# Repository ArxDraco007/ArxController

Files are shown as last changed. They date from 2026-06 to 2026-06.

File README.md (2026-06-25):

# ArxController

## What is this?
A fully custom controller. Customizable according to your console. Firmware, 3D Models, and PCB design.

## Why did I make this?
Making your own controller is absolutely amazing! The process gives you a complete learning of wiring peripherals, Double LDO circuits, Battery charging protection, and the ESP32-WROOM module. This journey has been absolutely wonderful, and I would recommend this project for all intermediate PCB designers.

## PICTURES-


ArxControllerV2sleek
ArxControllerV2Desert
ArxControllerV2

## Zine - 
zine (6)

## Build Instructions -
Soldering -
Start by applying flux to the pads on the footprint where you'll be soldering. Tin one of the pads with a small amount of solder, then carefully place your component onto the footprint. Touch your iron to the tinned pad to reflow it and tack the component in place, then let go with your tweezers once it's sitting right. Move to the opposite pad and solder it properly to the component. Finally, go back to your first pad and add a bit more solder to make sure you've got a solid joint.
Firmware - 
Plug in the ESP32-S3 via USB-C, select Board "ESP32S3 Dev Module" and the correct Port, hold BOOT while plugging in (or while pressing RESET) if it doesn't auto-detect, then click Upload to flash it, and finally press RESET or replug to run the new firmware.

## BOM

| Reference | Qty | Value | Footprint | Source | Buy Link |
|---|---|---|---|---|---|
| R2,R3 | 2 | 5.1k | Resistor_SMD:R_0603_1608Metric | Robu.in | [Link](https://robu.in/product/rc0603jr-075k1l-yageo-res-thick-film-0603-5-1k-ohm-5-0-1w1-10w-%C2%B1100ppm-c-pad-smd-t-r/) |
| R4 | 1 | 1.2k | Resistor_SMD:R_0603_1608Metric | LCSC | [Link](https://www.lcsc.com/search?q=0603+1.2K+ohm+resistor) |
| R5,R6,R7 | 3 | 1k | Resistor_SMD:R_0603_1608Metric | Robu.in | [Link](https://robu.in/product/1k-ohm-1-4w-0603-surface-mount-chip-resistor-pack-of-100/) |
| R8,R9 | 2 | 100R | Resistor_SMD:R_0603_1608Metric | LCSC | [Link](https://www.lcsc.com/search?q=0603+100R+1%25+resistor) |
| R10,R11,R12,R13,R14,R15,R16 | 7 | 100k | Resistor_SMD:R_0603_1608Metric | Robu.in | [Link](https://robu.in/product/100k-ohm-1-4w-0603-surface-mount-chip-resistor-pack-of-100/) |
| SW1 | 1 | EN (Tactile SMD) | Button_Switch_SMD:SW_SPST_TS-1088-xR020 | LCSC | [Link](https://www.lcsc.com/search?q=TS-1088) |
| SW2 | 1 | SW_PWR (Header) | Connector_PinSocket_2.54mm:PinSocket_1x03_P2.54mm_Vertical | Robu.in | [Link](https://robu.in/product/2-54mm-female-header-1x40-pin-strip/) |
| SW3 | 1 | BOOT (Tactile SMD) | custom_footprints:SW_SPST_TS-1088-xR020 | LCSC | [Link](https://www.lcsc.com/search?q=TS-1088) |
| SW4 | 1 | BTN_L (Shoulder switch) | custom_footprints:TS-1224VW | LCSC | [Link](https://www.lcsc.com/search?q=TS-1224VW) |
| SW5 | 1 | BTN_UP (Tactile 8mm) | custom_footprints:SW_PUSH_8mm_H5mm_custom | Robu.in | [Link](https://robu.in/product/6x6x5mm-tactile-push-button-switch-pack-of-10/) |
| SW6 | 1 | BTN_LEFT (Tactile 8mm) | custom_footprints:SW_PUSH_8mm_H5mm_custom | Robu.in | [Link](https://robu.in/product/6x6x5mm-tactile-push-button-switch-pack-of-10/) |
| SW7 | 1 | BTN_DOWN (Tactile 8mm) | custom_footprints:SW_PUSH_8mm_H5mm_custom | Robu.in | [Link](https://robu.in/product/6x6x5mm-tactile-push-button-switch-pack-of-10/) |
| SW8 | 1 | BTN_RIGHT (Tactile 8mm) | custom_footprints:SW_PUSH_8mm_H5mm_custom | Robu.in | [Link](https://robu.in/product/6x6x5mm-tactile-push-button-switch-pack-of-10/) |
| SW9 | 1 | BTN_START (Tactile 8mm) | custom_footprints:SW_PUSH_8mm_H5mm_custom | Robu.in | [Link](https://robu.in/product/6x6x5mm-tactile-push-button-switch-pack-of-10/) |
| SW10 | 1 | BTN_R (Shoulder switch) | custom_footprints:TS-1224VW | LCSC | [Link](https://www.lcsc.com/search?q=TS-1224VW) |
| SW11 | 1 | BTN_X (Tactile 8mm) | custom_footprints:SW_PUSH_8mm_H5mm_custom | Robu.in | [Link](https://robu.in/product/6x6x5mm-tactile-push-button-switch-pack-of-10/) |
| SW12 | 1 | BTN_A (Tactile 8mm) | custom_footprints:SW_PUSH_8mm_H5mm_custom | Robu.in | [Link](https://robu.in/product/6x6x5mm-tactile-push-button-switch-pack-of-10/) |
| SW13 | 1 | BTN_B (Tactile 8mm) | custom_footprints:SW_PUSH_8mm_H5mm_custom | Robu.in | [Link](https://robu.in/product/6x6x5mm-tactile-push-button-switch-pack-of-10/) |
| SW14 | 1 | BTN_Y (Tactile 8mm) | custom_footprints:SW_PUSH_8mm_H5mm_custom | Robu.in | [Link](https://robu.in/product/6x6x5mm-tactile-push-button-switch-pack-of-10/) |
| SW15 | 1 | BTN_SELECT (Tactile 8mm) | custom_footprints:SW_PUSH_8mm_H5mm_custom | Robu.in | [Link](https://robu.in/product/6x6x5mm-tactile-push-button-switch-pack-of-10/) |
| SW16 | 1 | BTN_SYS (Tactile 8mm) | custom_footprints:SW_PUSH_8mm_H5mm_custom | Robu.in | [Link](https://robu.in/product/6x6x5mm-tactile-push-button-switch-pack-of-10/) |
| TP1,TP3,TP5 | 3 | TestPoint | TestPoint:TestPoint_Pad_D2.0mm | Robu.in | [Link](https://robu.in/product/2mm-pin-female-header-1x40/) |
| TP4 | 1 | AMS_3V3 (TestPoint) | TestPoint:TestPoint_Pad_D2.0mm | Robu.in | [Link](https://robu.in/product/2mm-pin-female-header-1x40/) |
| U1 | 1 | ESP32-S3-WROOM-1-N16R8 | RF_Module:ESP32-S3-WROOM-1 | Robu.in | [Link](https://robu.in/product/espressif-esp32-s3-wroom-1-n16r8-module/) |
| U2 | 1 | MIC5219-3.3YM5 | Package_TO_SOT_SMD:SOT-23-5 | Robu.in | [Link](https://robu.in/product/mic5219-3-3ym5-tr-microchip-fixed-ldo-voltage-regulator-2-5v-to-12v-350mv-dropout-3-3vout-500maout-sot-23-5/) |
| U3 | 1 | TP4056-42-ESOP8 | Package_SO:SOIC-8-1EP_3.9x4.9mm_P1.27mm_EP2.41x3.3mm_ThermalVias | Robu.in | [Link](https://robu.in/product/tp4056-top-power-asic-4-2v-1a-standalone-linear-li-ion-battery-charger-with-thermal-regulation-sop8/) |
| U4 | 1 | DW01A | Package_TO_SOT_SMD:SOT-23-6 | Robu.in | [Link](https://robu.in/product/dw01a-4-3v-lithium-ion-lithium-polymer-battery-protection-ic-6pin-sot-23/) |
| U5 | 1 | AMS1117-3.3 | Package_TO_SOT_SMD:SOT-223-3_TabPin2 | Robu.in | [Link](https://robu.in/product/ams1117-3-3-slkor-800ma-70db120hz-fixed-3-3v-positive-electrode-18v-sot-223-voltage-regulators-linear-low-drop-out-ldo-regulators-rohs/) |
| U6 | 1 | PCM5102APWR | TSSOP-20 | Robu.in | [Link](https://robu.in/product/pcm5102apwr-texas-instruments-digital-to-analogue-converter-32-bit-384-ksps-i2s-3v-to-3-6v-tssop-20-pins/) |
| U7 | 1 | TPA2012D2 | QFN-16 | LCSC | [Link](https://www.lcsc.com/search?q=TPA2012D2) |
| U8 | 1 | ILI9341 TFT 2.4/2.8" Display Module | SPI 240x320 | LCSC | [Link](https://www.lcsc.com/search?q=ILI9341+2.8+SPI) |
| U9 | 1 | MAX17048G+T10 | SOT-23-6 (USOP-8) | LCSC | [Link](https://www.lcsc.com/search?q=MAX17048) |
| U10 | 1 | XC6220 LDO | SOT-23-5 | LCSC | [Link](https://www.lcsc.com/search?q=XC6220) |
| - | 1 | microSD Card Slot (Push-Push) | SMD microSD Socket | Robu.in | [Link](https://robu.in/product/micro-sd-card-tf-card-memory-card-socket-push-push-type-smd/) |
| - | 1 | USB-C Connector (16-pin) | USB_C_Receptacle_USB2.0_16P | Robu.in | [Link](https://robu.in/product/usb-type-c-16-pin-female-connector-smd/) |
| HW1-HW4 | 4 | M3 × 22mm Machine Screw | Mechanical:MountingHardware | element14 | [Link](https://in.element14.com/tr-fastenings/tr00008755-000/screw-flat-csk-head-sltd-m3-22mm/dp/4156380) |
| HW5-HW8 | 4 | M3 Hex Nut | Mechanical:MountingHardware | FlyRobo | [Link](https://www.flyrobo.in/m3-ss-hex-nut-10pcs?srsltid=AfmBOopC71qpsOIubiWPyQa1-qcC8mzI4XCSzNWDzo-gBculU_eEorxn) |
| FNIRSI HS-02 | 1 | Soldering | Soldering Iron | FNIRSI | [Link]("https://rees52.com/products/fnirsi-hs-01-intelligent-soldering-iron-hs-01-intelligent-temperature-controlled-soldering-iron-hs-01-automatic-sleep-mode-soldering-stat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")

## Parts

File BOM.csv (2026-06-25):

Reference | Qty | Value | Footprint | Source | Buy Link (India)
R2,R3 | 2 | 5.1k | Resistor_SMD:R_0603_1608Metric | Robu.in | https://robu.in/product/rc0603jr-075k1l-yageo-res-thick-film-0603-5-1k-ohm-5-0-1w1-10w-%C2%B1100ppm-c-pad-smd-t-r/
R4 | 1 | 1.2k | Resistor_SMD:R_0603_1608Metric | LCSC | https://www.lcsc.com/search?q=0603+1.2K+ohm+resistor
R5,R6,R7 | 3 | 1k | Resistor_SMD:R_0603_1608Metric | Robu.in | https://robu.in/product/1k-ohm-1-4w-0603-surface-mount-chip-resistor-pack-of-100/
R8,R9 | 2 | 100R | Resistor_SMD:R_0603_1608Metric | LCSC | https://www.lcsc.com/search?q=0603+100R+1%25+resistor
R10,R11,R12,R13,R14,R15,R16 | 7 | 100k | Resistor_SMD:R_0603_1608Metric | Robu.in | https://robu.in/product/100k-ohm-1-4w-0603-surface-mount-chip-resistor-pack-of-100/
SW1 | 1 | EN (Tactile SMD) | Button_Switch_SMD:SW_SPST_TS-1088-xR020 | LCSC | https://www.lcsc.com/search?q=TS-1088
SW2 | 1 | SW_PWR (Header) | Connector_PinSocket_2.54mm:PinSocket_1x03_P2.54mm_Vertical | Robu.in | https://robu.in/product/2-54mm-female-header-1x40-pin-strip/
SW3 | 1 | BOOT (Tactile SMD) | custom_footprints:SW_SPST_TS-1088-xR020 | LCSC | https://www.lcsc.com/search?q=TS-1088
SW4 | 1 | BTN_L (Shoulder switch) | custom_footprints:TS-1224VW | LCSC | https://www.lcsc.com/search?q=TS-1224VW
SW5 | 1 | BTN_UP (Tactile 8mm) | custom_footprints:SW_PUSH_8mm_H5mm_custom | Robu.in | https://robu.in/product/6x6x5mm-tactile-push-button-switch-pack-of-10/
SW6 | 1 | BTN_LEFT (Tactile 8mm) | custom_footprints:SW_PUSH_8mm_H5mm_custom | Robu.in | https://robu.in/product/6x6x5mm-tactile-push-button-switch-pack-of-10/
SW7 | 1 | BTN_DOWN (Tactile 8mm) | custom_footprints:SW_PUSH_8mm_H5mm_custom | Robu.in | https://robu.in/product/6x6x5mm-tactile-push-button-switch-pack-of-10/
SW8 | 1 | BTN_RIGHT (Tactile 8mm) | custom_footprints:SW_PUSH_8mm_H5mm_custom | Robu.in | https://robu.in/product/6x6x5mm-tactile-push-button-switch-pack-of-10/
SW9 | 1 | BTN_START (Tactile 8mm) | custom_footprints:SW_PUSH_8mm_H5mm_custom | Robu.in | https://robu.in/product/6x6x5mm-tactile-push-button-switch-pack-of-10/
SW10 | 1 | BTN_R (Shoulder switch) | custom_footprints:TS-1224VW | LCSC | https://www.lcsc.com/search?q=TS-1224VW
SW11 | 1 | BTN_X (Tactile 8mm) | custom_footprints:SW_PUSH_8mm_H5mm_custom | Robu.in | https://robu.in/product/6x6x5mm-tactile-push-button-switch-pack-of-10/
SW12 | 1 | BTN_A (Tactile 8mm) | custom_footprints:SW_PUSH_8mm_H5mm_custom | Robu.in | https://robu.in/product/6x6x5mm-tactile-push-button-switch-pack-of-10/
SW13 | 1 | BTN_B (Tactile 8mm) | custom_footprints:SW_PUSH_8mm_H5mm_custom | Robu.in | https://robu.in/product/6x6x5mm-tactile-push-button-switch-pack-of-10/
SW14 | 1 | BTN_Y (Tactile 8mm) | custom_footprints:SW_PUSH_8mm_H5mm_custom | Robu.in | https://robu.in/product/6x6x5mm-tactile-push-button-switch-pack-of-10/
SW15 | 1 | BTN_SELECT (Tactile 8mm) | custom_footprints:SW_PUSH_8mm_H5mm_custom | Robu.in | https://robu.in/product/6x6x5mm-tactile-push-button-switch-pack-of-10/
SW16 | 1 | BTN_SYS (Tactile 8mm) | custom_footprints:SW_PUSH_8mm_H5mm_custom | Robu.in | https://robu.in/product/6x6x5mm-tactile-push-button-switch-pack-of-10/
TP1,TP3,TP5 | 3 | TestPoint | TestPoint:TestPoint_Pad_D2.0mm | Robu.in | https://robu.in/product/2mm-pin-female-header-1x40/
TP4 | 1 | AMS_3V3 (TestPoint) | TestPoint:TestPoint_Pad_D2.0mm | Robu.in | https://robu.in/product/2mm-pin-female-header-1x40/
U1 | 1 | ESP32-S3-WROOM-1-N16R8 | RF_Module:ESP32-S3-WROOM-1 | Robu.in | https://robu.in/product/espressif-esp32-s3-wroom-1-n16r8-module/
U2 | 1 | MIC5219-3.3YM5 | Package_TO_SOT_SMD:SOT-23-5 | Robu.in | https://robu.in/product/mic5219-3-3ym5-tr-microchip-fixed-ldo-voltage-regulator-2-5v-to-12v-350mv-dropout-3-3vout-500maout-sot-23-5/
U3 | 1 | TP4056-42-ESOP8 | Package_SO:SOIC-8-1EP_3.9x4.9mm_P1.27mm_EP2.41x3.3mm_ThermalVias | Robu.in | https://robu.in/product/tp4056-top-power-asic-4-2v-1a-standalone-linear-li-ion-battery-charger-with-thermal-regulation-sop8/
U4 | 1 | DW01A | Package_TO_SOT_SMD:SOT-23-6 | Robu.in | https://robu.in/product/dw01a-4-3v-lithium-ion-lithium-polymer-battery-protection-ic-6pin-sot-23/
U5 | 1 | AMS1117-3.3 | Package_TO_SOT_SMD:SOT-223-3_TabPin2 | Robu.in | https://robu.in/product/ams1117-3-3-slkor-800ma-70db120hz-fixed-3-3v-positive-electrode-18v-sot-223-voltage-regulators-linear-low-drop-out-ldo-regulators-rohs/
U6 | 1 | PCM5102APWR | TSSOP-20 | Robu.in | https://robu.in/product/pcm5102apwr-texas-instruments-digital-to-analogue-converter-32-bit-384-ksps-i2s-3v-to-3-6v-tssop-20-pins/
U7 | 1 | TPA2012D2 | QFN-16 | LCSC | https://www.lcsc.com/search?q=TPA2012D2
U8 | 1 | ILI9341 TFT 2.4 Display Module | SPI 240x320 | LCSC | https://www.lcsc.com/search?q=ILI9341+2.8+SPI
U9 | 1 | MAX17048G+T10 | SOT-23-6 (USOP-8) | LCSC | https://www.lcsc.com/search?q=MAX17048
U10 | 1 | XC6220 LDO | SOT-23-5 | LCSC | https://www.lcsc.com/search?q=XC6220
MicroSD | 1 | microSD Card Slot (Push-Push) | SMD microSD Socket | Robu.in | https://robu.in/product/micro-sd-card-tf-card-memory-card-socket-push-push-type-smd/
USB Connector Pin | 1 | USB-C Connector (16-pin) | USB_C_Receptacle_USB2.0_16P | Robu.in | https://robu.in/product/usb-type-c-16-pin-female-connector-smd/
HW1-HW4 | 4 | M3 × 22mm Machine Screw | Mechanical:MountingHardware | element14 | https://in.element14.com/tr-fastenings/tr00008755-000/screw-flat-csk-head-sltd-m3-22mm/dp/4156380
HW5-HW8 | 4 | M3 Hex Nut | Mechanical:MountingHardware | FlyRobo | https://www.flyrobo.in/m3-ss-hex-nut-10pcs
FNIRSI HS-02 | 1 | Soldering | Soldering Iron | FNIRSI | https://rees52.com/products/fnirsi-hs-01-intelligent-soldering-iron-hs-01-intelligent-temperature-controlled-soldering-iron-hs-01-automatic-sleep-mode-solderi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

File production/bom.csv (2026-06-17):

Designator | Footprint | Quantity | Value | LCSC Part #
C1, C13, C3 | 0603 | 3 | 100nF
C10, C4, C5, C6 | 0603 | 4 | 10uF
C11 | CP_EIA-3216-18_Kemet-A | 1 | 10uF
C12 | CP_EIA-3216-18_Kemet-A | 1 | 22uF
C2 | 0603 | 1 | 22nF
C7, C8, C9 | 0603 | 3 | 100uF
D1 | 0603 | 1 | RED
D2 | 0603 | 1 | BLUE
J1 | USB_C_Receptacle_GCT_USB4105-xx-A_16P_TopMnt_Horizontal | 1 | USB_C_Receptacle_USB2.0_16P
J2 | JST_ZH_S2B-ZR-SM4A-TF_1x02-1MP_P1.50mm_Horizontal | 1 | BATT_Conn
J4 | OLED128x32_1x04_P2.54mm_socket | 1 | OLED_Conn
Q1 | SOT-23-6L_TCP | 1 | ~
Q2 | SOT-23 | 1 | PMOS
R1, R17 | 0603 | 2 | 10k
R10, R11, R12, R13, R14, R15, R16 | 0603 | 7 | 100k
R2, R3 | 0603 | 2 | 5.1k
R4 | 0603 | 1 | 1.2k
R5, R6, R7 | 0603 | 3 | 1k
R8, R9 | 0603 | 2 | 100R
SW1 | SW_SPST_TS-1088-xR020 | 1 | EN
SW10 | TS-1224VW | 1 | BTN_R
SW11 | SW_PUSH_8mm_H5mm_custom | 1 | BTN_X
SW12 | SW_PUSH_8mm_H5mm_custom | 1 | BTN_A
SW13 | SW_PUSH_8mm_H5mm_custom | 1 | BTN_B
SW14 | SW_PUSH_8mm_H5mm_custom | 1 | BTN_Y
SW15 | SW_PUSH_8mm_H5mm_custom | 1 | BTN_SELECT
SW16 | SW_PUSH_8mm_H5mm_custom | 1 | BTN_SYS
SW2 | PinSocket_1x03_P2.54mm_Vertical | 1 | SW_PWR
SW3 | SW_SPST_TS-1088-xR020 | 1 | BOOT
SW4 | TS-1224VW | 1 | BTN_L
SW5 | SW_PUSH_8mm_H5mm_custom | 1 | BTN_UP
SW6 | SW_PUSH_8mm_H5mm_custom | 1 | BTN_LEFT
SW7 | SW_PUSH_8mm_H5mm_custom | 1 | BTN_DOWN
SW8 | SW_PUSH_8mm_H5mm_custom | 1 | BTN_RIGHT
SW9 | SW_PUSH_8mm_H5mm_custom | 1 | BTN_START
TP1, TP3, TP5 | TestPoint_Pad_D2.0mm | 3 | TestPoint
TP4 | TestPoint_Pad_D2.0mm | 1 | AMS_3V3
U1 | ESP32-S3-WROOM-1 | 1 | ESP32-S3-WROOM-1
U2 | SOT-23-5 | 1 | MIC5219-3.3YM5
U3 | SOIC-8-1EP_3.9x4.9mm_P1.27mm_EP2.41x3.3mm_ThermalVias | 1 | TP4056-42-ESOP8
U4 | SOT-23-6 | 1 | DW01A
U5 | SOT-223-3_TabPin2 | 1 | AMS1117-3.3

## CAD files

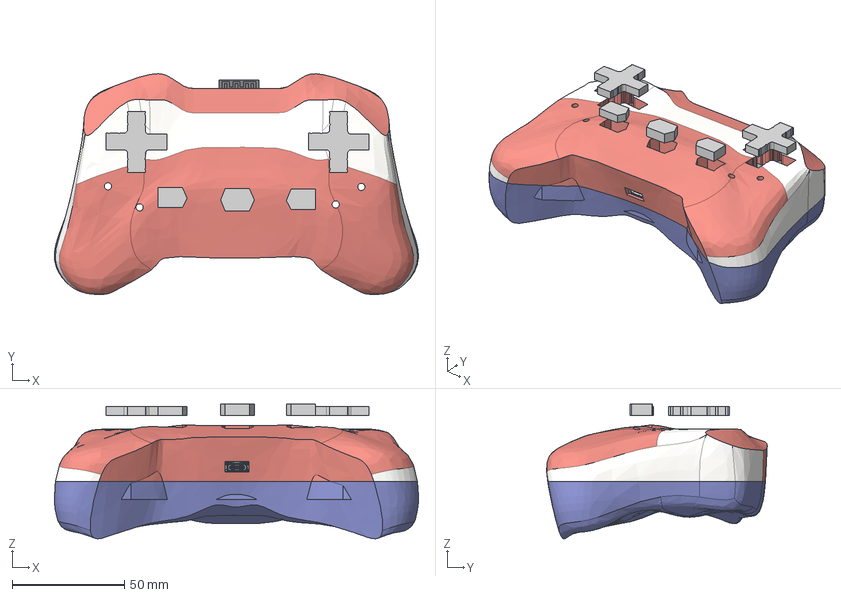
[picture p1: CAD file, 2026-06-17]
CAD/Assembly.step
162.0 x 98.2 x 59.9 mm

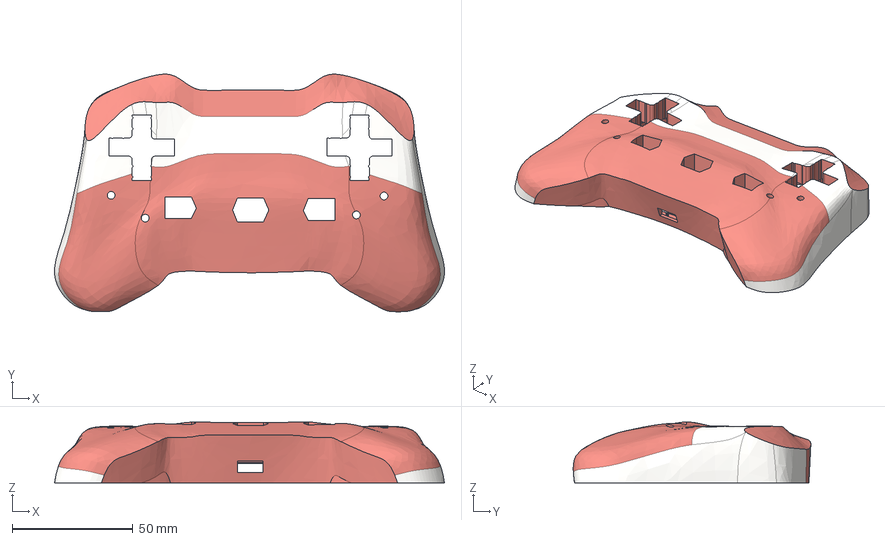
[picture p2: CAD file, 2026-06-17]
CAD/top.step
161.2 x 98.3 x 25.2 mm

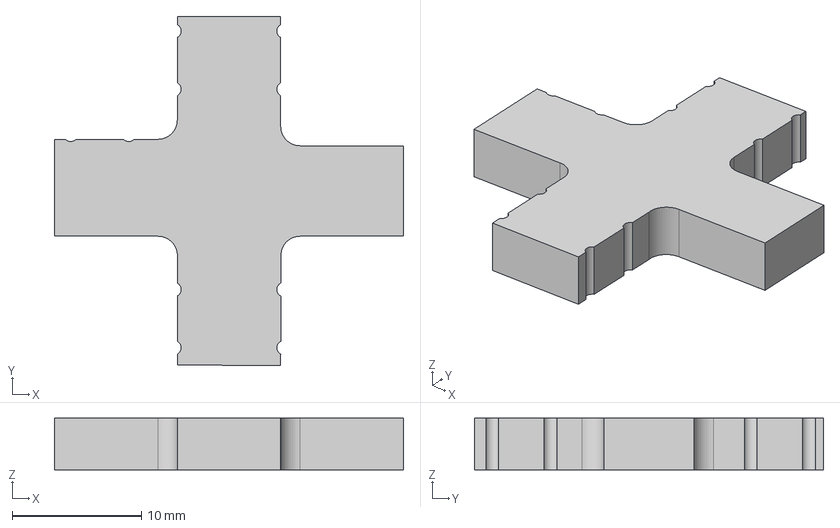
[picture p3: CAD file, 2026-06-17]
CAD/plusbutton.step
27.0 x 27.0 x 4.00 mm

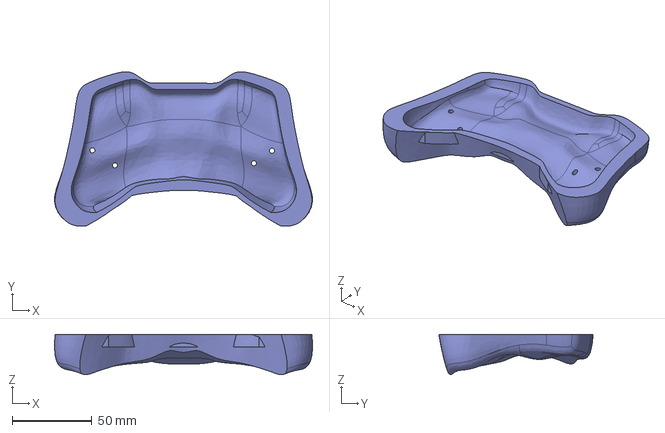
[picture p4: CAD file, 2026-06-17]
CAD/bottom.step
162.0 x 96.9 x 25.4 mm

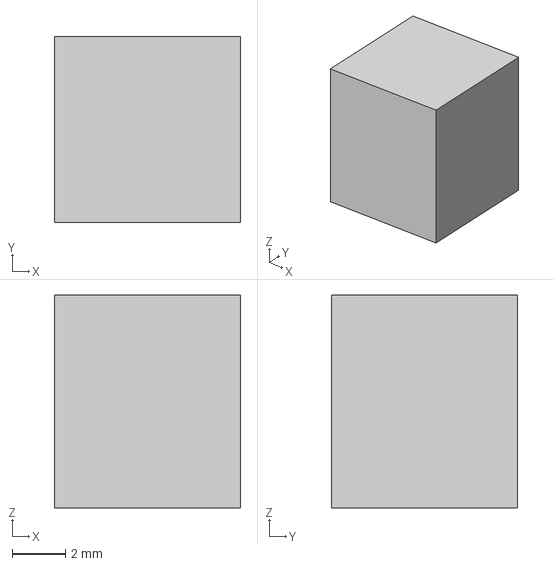
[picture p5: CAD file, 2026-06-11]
CAD/squarebutton.step
7.00 x 7.00 x 8.00 mm
91292A020_18-8 Stainless Steel Socket Head Screw
90870A113_Zinc-Plated High-Strength Steel Hex Nut x 8

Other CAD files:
CAD/Assembly.f3z

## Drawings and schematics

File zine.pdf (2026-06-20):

# ARX

# CONTROLLER

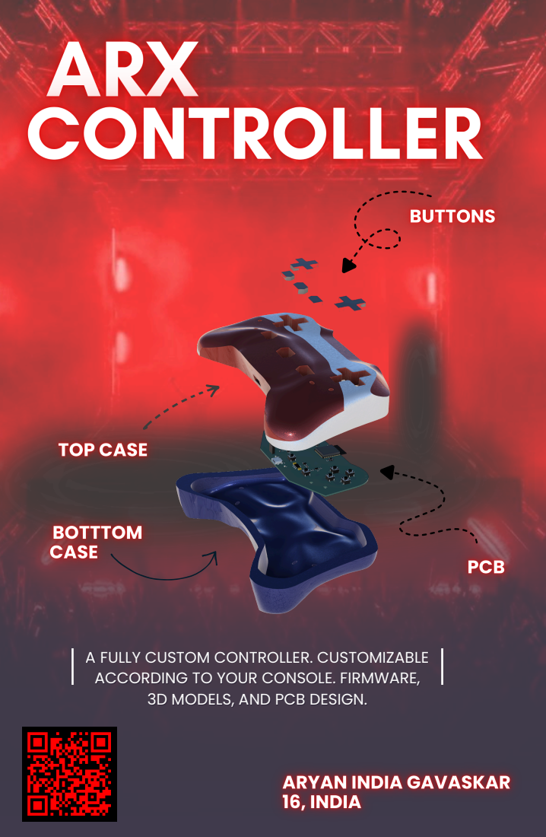
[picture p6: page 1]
BOTTTOM CASE; PCB; TOP CASE; BUTTONS

A FULLY CUSTOM CONTROLLER. CUSTOMIZABLE
ACCORDING TO YOUR CONSOLE. FIRMWARE,
3D MODELS, AND PCB DESIGN.

ARYAN INDIA GAVASKAR
16, INDIA

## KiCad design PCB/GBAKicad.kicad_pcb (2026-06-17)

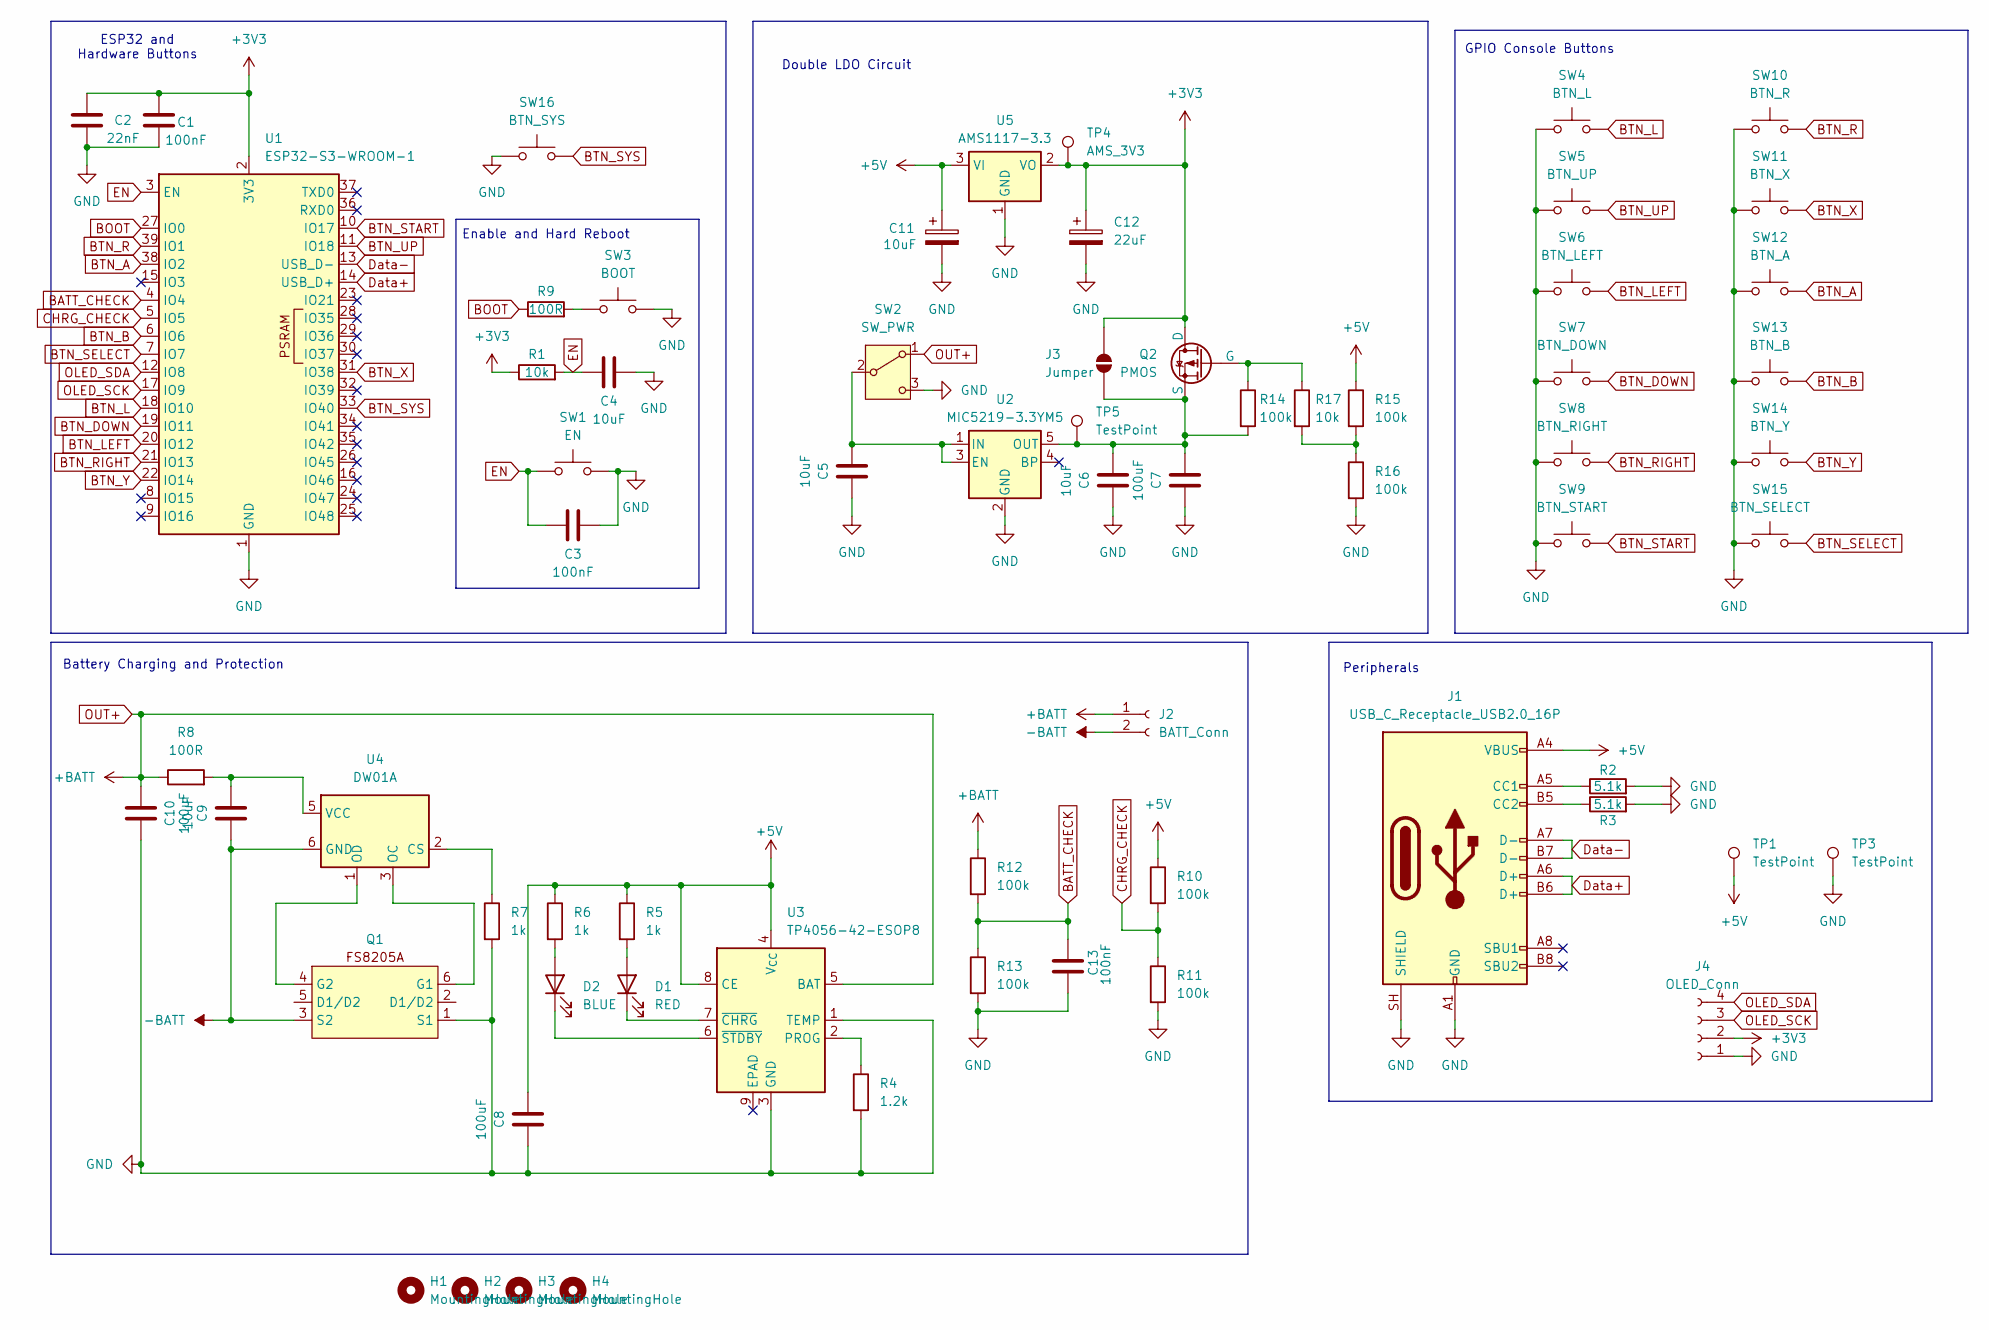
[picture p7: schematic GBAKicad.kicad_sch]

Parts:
C1, C3, C13: 100nF; C_0603_1608Metric
C2: 22nF; C_0603_1608Metric
C4, C5, C6, C10: 10uF; C_0603_1608Metric
C7, C8, C9: 100uF; C_0603_1608Metric
C11: 10uF; CP_EIA-3216-18_Kemet-A
C12: 22uF; CP_EIA-3216-18_Kemet-A
D1: RED; LED_0603_1608Metric
D2: BLUE; LED_0603_1608Metric
H1, H2, H3, H4: MountingHole; MountingHole_3.2mm_M3
J1: USB_C_Receptacle_USB2.0_16P; USB_C_Receptacle_GCT_USB4105-xx-A_16P_TopMnt_Horizontal
J2: BATT_Conn; JST_ZH_S2B-ZR-SM4A-TF_1x02-1MP_P1.50mm_Horizontal
J3: Jumper; R_0603_1608Metric
J4: OLED_Conn; OLED128x32_1x04_P2.54mm_socket
Q1: SOT-23-6L_TCP
Q2: PMOS; SOT-23
R1, R17: 10k; R_0603_1608Metric
R2, R3: 5.1k; R_0603_1608Metric
R4: 1.2k; R_0603_1608Metric
R5, R6, R7: 1k; R_0603_1608Metric
R8, R9: 100R; R_0603_1608Metric
R10, R11, R12, R13, R14, R15, R16: 100k; R_0603_1608Metric
SW1: EN; SW_SPST_TS-1088-xR020
SW2: SW_PWR; PinSocket_1x03_P2.54mm_Vertical
SW3: BOOT; SW_SPST_TS-1088-xR020
SW4: BTN_L; TS-1224VW
SW5: BTN_UP; SW_PUSH_8mm_H5mm_custom
SW6: BTN_LEFT; SW_PUSH_8mm_H5mm_custom
SW7: BTN_DOWN; SW_PUSH_8mm_H5mm_custom
SW8: BTN_RIGHT; SW_PUSH_8mm_H5mm_custom
SW9: BTN_START; SW_PUSH_8mm_H5mm_custom
SW10: BTN_R; TS-1224VW
SW11: BTN_X; SW_PUSH_8mm_H5mm_custom
SW12: BTN_A; SW_PUSH_8mm_H5mm_custom
SW13: BTN_B; SW_PUSH_8mm_H5mm_custom
SW14: BTN_Y; SW_PUSH_8mm_H5mm_custom
SW15: BTN_SELECT; SW_PUSH_8mm_H5mm_custom
SW16: BTN_SYS; SW_PUSH_8mm_H5mm_custom
TP1, TP3, TP5: TestPoint; TestPoint_Pad_D2.0mm
TP4: AMS_3V3; TestPoint_Pad_D2.0mm
U1: ESP32-S3-WROOM-1
U2: MIC5219-3.3YM5; SOT-23-5
U3: TP4056-42-ESOP8; SOIC-8-1EP_3.9x4.9mm_P1.27mm_EP2.41x3.3mm_ThermalVias
U4: DW01A; SOT-23-6
U5: AMS1117-3.3; SOT-223-3_TabPin2

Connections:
+3V3: C1.2, C2.2, C12.1, J3.2 (B), J4.2, Q2.1 (D), R1.1, TP4.1 (1_1), U1.2 (3V3), U5.2 (VO)
+5V: C8.1, C11.1, J1.A4 (VBUS), J1.A9 (VBUS), J1.B4 (VBUS), J1.B9 (VBUS), R5.1, R6.1, R10.1, R15.1, TP1.1 (1_1), U3.4 (V_{CC}), U3.8 (CE), U5.3 (VI)
-BATT: C9.2, J2.2, Q1.3 (S2), U4.6 (GND)
BATT_CHECK: C13.1, R12.2, R13.1, U1.4 (IO4)
BOOT: R9.1, U1.27 (IO0)
BTN_A: SW12.2, U1.38 (IO2)
BTN_B: SW13.2, U1.6 (IO6)
BTN_DOWN: SW7.2, U1.19 (IO11)
BTN_L: SW4.2, U1.18 (IO10)
BTN_LEFT: SW6.2, U1.20 (IO12)
BTN_R: SW10.2, U1.39 (IO1)
BTN_RIGHT: SW8.2, U1.21 (IO13)
BTN_SELECT: SW15.2, U1.7 (IO7)
BTN_START: SW9.2, U1.10 (IO17)
BTN_SYS: SW16.2, U1.33 (IO40)
BTN_UP: SW5.2, U1.11 (IO18)
BTN_X: SW11.2, U1.31 (IO38)
BTN_Y: SW14.2, U1.22 (IO14)
CHRG_CHECK: R10.2, R11.1, U1.5 (IO5)
Data+: J1.A6 (D+), J1.B6 (D+), U1.14 (USB_D+)
Data-: J1.A7 (D-), J1.B7 (D-), U1.13 (USB_D-)
EN: C3.1, C4.1, R1.2, SW1.1, U1.3 (EN)
GND: C1.1, C2.1, C3.2, C4.2, C5.2, C6.2, C7.2, C8.2, C10.1, C11.2, C12.2, C13.2, J1.A1 (GND), J1.A12 (GND), J1.B1 (GND), J1.B12 (GND), J1.SH (SHIELD), J4.1, Q1.1 (S1), R2.2, R3.2, R4.2, R7.2, R11.2, R13.2, R16.2, SW1.2, SW2.3 (C), SW3.2, SW4.1, SW5.1, SW6.1, SW7.1, SW8.1, SW9.1, SW10.1, SW11.1, SW12.1, SW13.1, SW14.1, SW15.1, SW16.1, TP3.1 (1_1), U1.1 (GND), U1.40 (GND), U1.41 (GND), U2.2 (GND), U3.1 (TEMP), U3.3 (GND), U5.1 (GND)
unnamed: D1.2 (A), R5.2
unnamed: D1.1 (K), U3.7 (~CHRG)
unnamed: D2.2 (A), R6.2
unnamed: D2.1 (K), U3.6 (~STDBY)
unnamed: J1.A5 (CC1), R2.1
unnamed: J1.B5 (CC2), R3.1
unnamed: C6.1, C7.1, J3.1 (A), Q2.3 (S), R14.2, TP5.1 (1_1), U2.5 (OUT)
unnamed: Q1.6 (G1), U4.3 (OC)
unnamed: Q1.4 (G2), U4.1 (OD)
unnamed: Q2.2 (G), R14.1, R17.1
unnamed: R9.2, SW3.1
unnamed: R15.2, R16.1, R17.2
unnamed: C5.1, SW2.2 (B), U2.1 (IN), U2.3 (EN)
unnamed: R4.1, U3.2 (PROG)
unnamed: R7.1, U4.2 (CS)
unnamed: C9.1, R8.2, U4.5 (VCC)
OLED_SCK: J4.3, U1.17 (IO9)
OLED_SDA: J4.4, U1.12 (IO8)
OUT+: C10.2, J2.1, R8.1, R12.1, SW2.1 (A), U3.5 (BAT)

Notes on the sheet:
Battery Charging and Protection
Double LDO Circuit
GPIO Console Buttons
Peripherals
Enable and Hard Reboot
ESP32 and Hardware Buttons

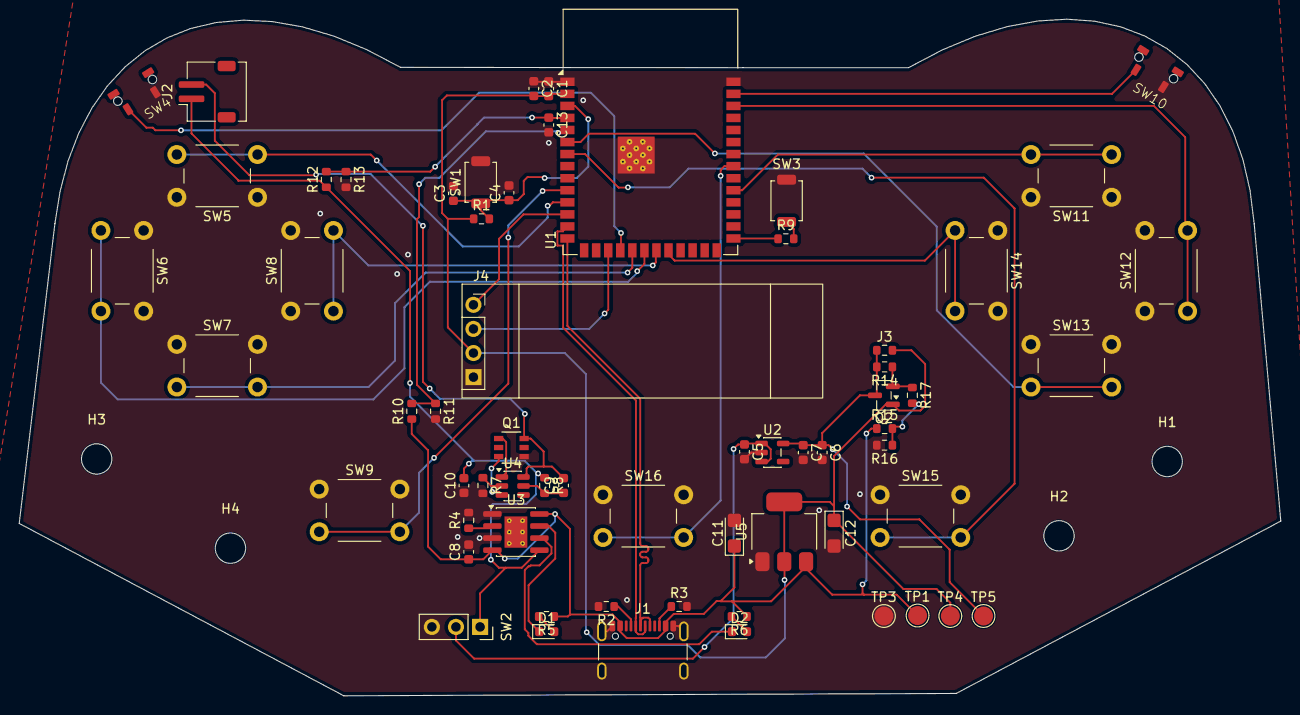
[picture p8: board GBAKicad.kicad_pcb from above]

Board: 2 copper layers, 132.9 x 71.3 mm, 67 parts (0 on the bottom side), 42 nets.

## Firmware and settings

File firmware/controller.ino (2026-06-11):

#include "USB.h"
#include "USBHIDGamepad.h"

USBHIDGamepad Gamepad;

#define BTN_UP 17
#define BTN_DOWN 11
#define BTN_LEFT 12
#define BTN_RIGHT 13
#define BTN_A 9
#define BTN_B 6
#define BTN_X 37
#define BTN_Y 48
#define BTN_L 39
#define BTN_R 0
#define BTN_START 15
#define BTN_SELECT 7
#define BTN_SYS 40

#define HID_BTN_A 1
#define HID_BTN_B 2
#define HID_BTN_X 3
#define HID_BTN_Y 4
#define HID_BTN_L 5
#define HID_BTN_R 6
#define HID_BTN_SELECT 7
#define HID_BTN_START 8
#define HID_BTN_SYS 9

void setup()
{
    pinMode(BTN_UP, INPUT_PULLUP);
    pinMode(BTN_DOWN, INPUT_PULLUP);
    pinMode(BTN_LEFT, INPUT_PULLUP);
    pinMode(BTN_RIGHT, INPUT_PULLUP);
    pinMode(BTN_A, INPUT_PULLUP);
    pinMode(BTN_B, INPUT_PULLUP);
    pinMode(BTN_X, INPUT_PULLUP);
    pinMode(BTN_Y, INPUT_PULLUP);
    pinMode(BTN_L, INPUT_PULLUP);
    pinMode(BTN_R, INPUT_PULLUP);
    pinMode(BTN_START, INPUT_PULLUP);
    pinMode(BTN_SELECT, INPUT_PULLUP);
    pinMode(BTN_SYS, INPUT_PULLUP);

    Gamepad.begin();
    USB.begin();
    delay(1000);
}

void loop()
{
    bool up = !digitalRead(BTN_UP);
    bool down = !digitalRead(BTN_DOWN);
    bool left = !digitalRead(BTN_LEFT);
    bool right = !digitalRead(BTN_RIGHT);

    int hatAngle = -1;
    if (up && right)
        hatAngle = 45;
    else if (down && right)
        hatAngle = 135;
    else if (down && left)
        hatAngle = 225;
    else if (up && left)
        hatAngle = 315;
    else if (up)
        hatAngle = 0;
    else if (right)
        hatAngle = 90;
    else if (down)
        hatAngle = 180;
    else if (left)
        hatAngle = 270;

    Gamepad.hat(hatAngle);

    if (!digitalRead(BTN_A))
        Gamepad.press(HID_BTN_A);
    else
        Gamepad.release(HID_BTN_A);
    if (!digitalRead(BTN_B))
        Gamepad.press(HID_BTN_B);
    else
        Gamepad.release(HID_BTN_B);
    if (!digitalRead(BTN_X))
        Gamepad.press(HID_BTN_X);
    else
        Gamepad.release(HID_BTN_X);
    if (!digitalRead(BTN_Y))
        Gamepad.press(HID_BTN_Y);
    else
        Gamepad.release(HID_BTN_Y);
    if (!digitalRead(BTN_L))
        Gamepad.press(HID_BTN_L);
    else
        Gamepad.release(HID_BTN_L);
    if (!digitalRead(BTN_R))
        Gamepad.press(HID_BTN_R);
    else
        Gamepad.release(HID_BTN_R);
    if (!digitalRead(BTN_SELECT))
        Gamepad.press(HID_BTN_SELECT);
    else
        Gamepad.release(HID_BTN_SELECT);
    if (!digitalRead(BTN_START))
        Gamepad.press(HID_BTN_START);
    else
        Gamepad.release(HID_BTN_START);
    if (!digitalRead(BTN_SYS))
        Gamepad.press(HID_BTN_SYS);
    else
        Gamepad.release(HID_BTN_SYS);

    Gamepad.send();
    delay(10);
}

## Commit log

2026-06-11 removing redundance
    [GBAKicad.kicad_pcb, GBAKicad.kicad_sch]
2026-06-17 CAD files
    [Assembly.f3z, Assembly.step, GBAKicad-NPTH-drl_map.dxf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]
2026-06-25 Add FNIRSI HS-02 soldering iron to BOM
    [BOM.csv]
